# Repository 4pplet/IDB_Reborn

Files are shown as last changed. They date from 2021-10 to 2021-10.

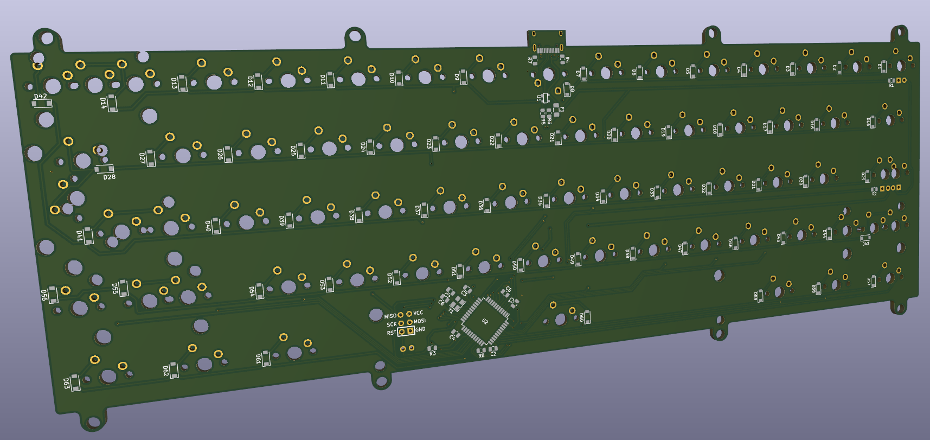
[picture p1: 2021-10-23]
Images/back.png

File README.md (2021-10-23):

# IDB_reborn
Reborn of the PCB for the IDB60

Made in KiCad Nightly

Originally designed by pngu.
Redigned by Mattelec.

Tested via private GB of the PCB. Might need some filing though.

Any question refer to Mattelec#9468 at Discord

Front

Back

Compatible layouts

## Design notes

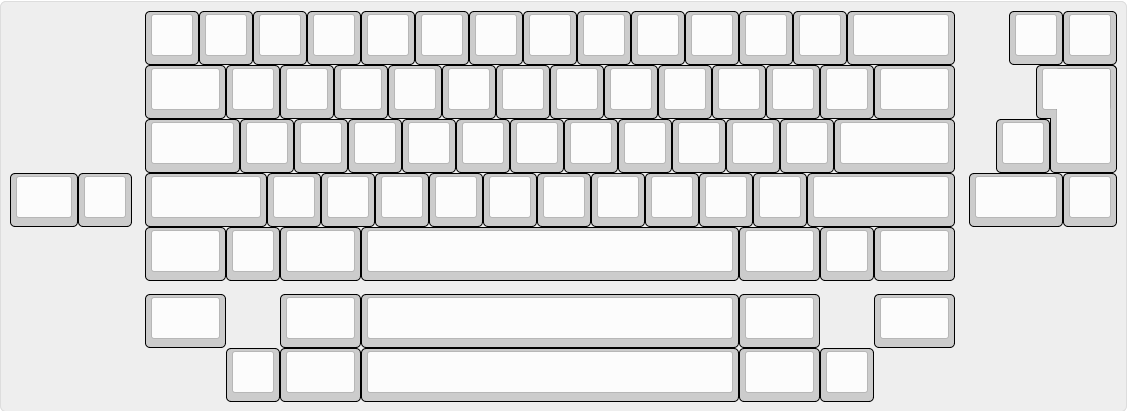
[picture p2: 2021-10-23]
Images/layout.png

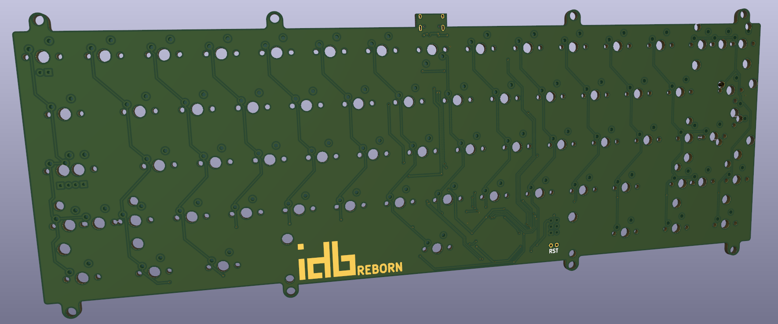
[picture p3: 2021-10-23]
Images/front.png

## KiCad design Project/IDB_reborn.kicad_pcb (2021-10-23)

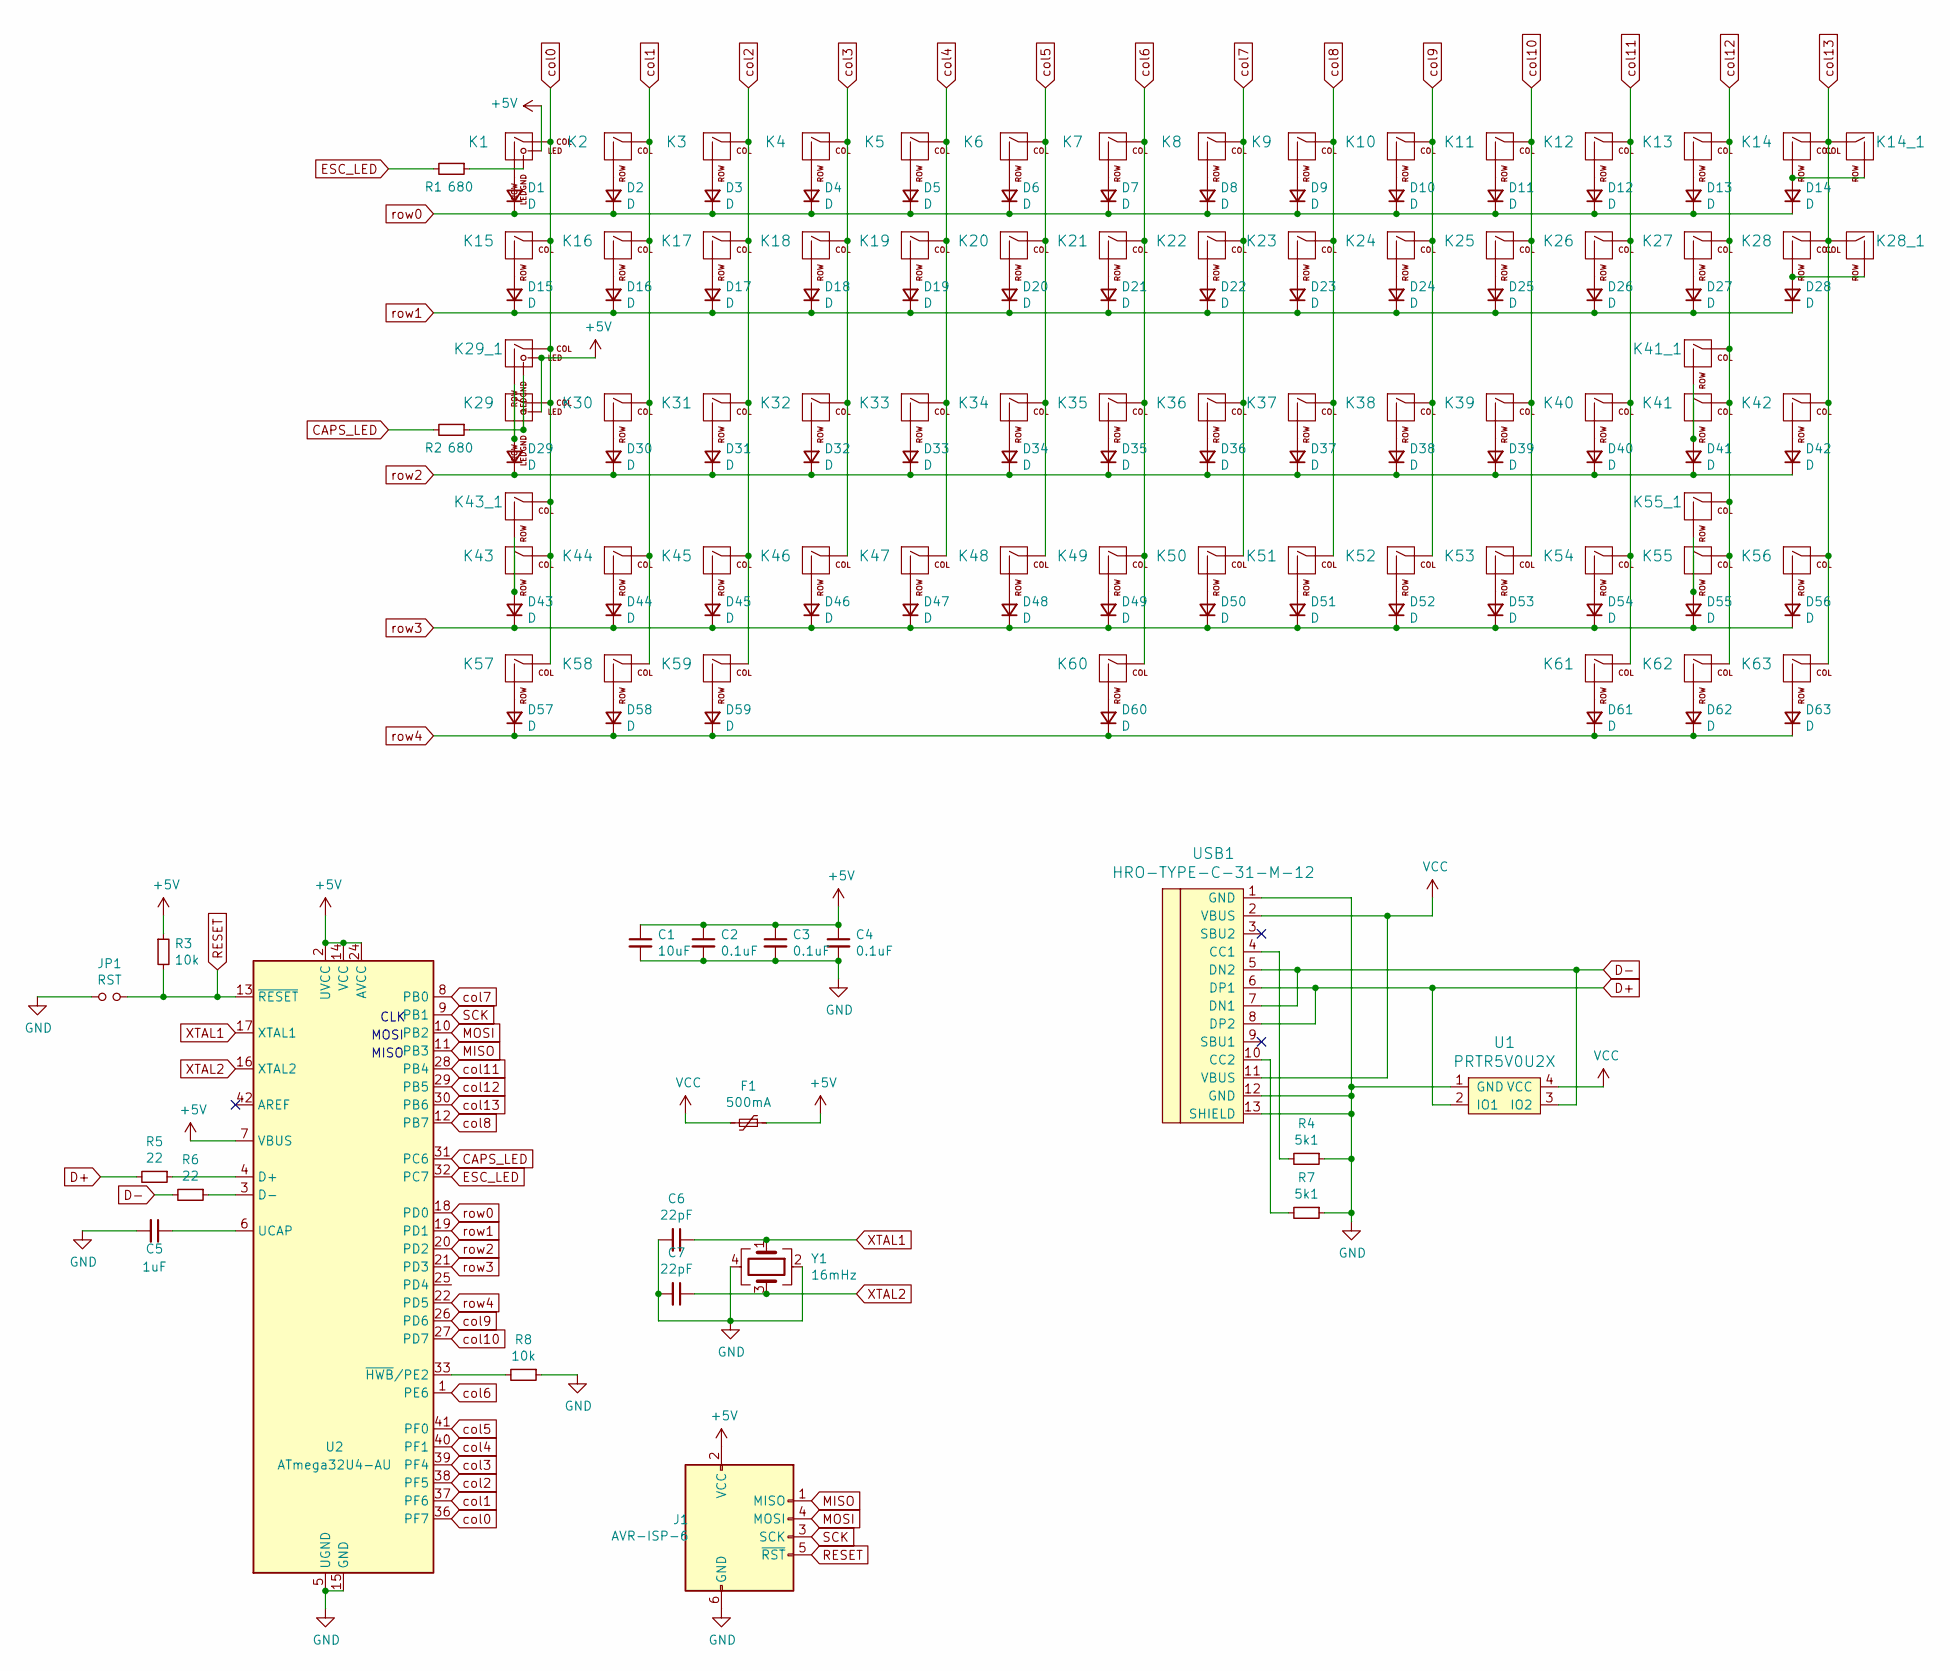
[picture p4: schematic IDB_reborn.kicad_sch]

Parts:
C1: 10uF; C_0805_2012Metric; LCSC C15850
C2, C3, C4: 0.1uF; C_0805_2012Metric; LCSC C49678
C5: 1uF; C_0805_2012Metric; LCSC C28323
C6, C7: 22pF; C_0805_2012Metric; LCSC C1804
D1, D2, D3, D4, D5, D6, D7, D8, D9, D10, D11, D12, D13, D14, D15, D16, D17, D18, D19, D20, D21, D22, D23, D24, D25, D26, D27, D28, D29, D30, D31, D32, D33, D34, D35, D36, D37, D38, D39, D40, D41, D42, D43, D44, D45, D46, D47, D48, D49, D50, D51, D52, D53, D54, D55, D56, D57, D58, D59, D60, D61, D62, D63: D; D_SOD-123-Pretty; LCSC C64898
F1: 500mA; Fuse_1206_3216Metric; LCSC C70076
J1: AVR-ISP-6; Reset_Pretty-Mask
JP1: RST; Reset_holes
K1: MXOnly-1U-19mm
K2, K3, K4, K5, K6, K7, K8, K9, K10, K11, K12, K13, K14_1, K16, K17, K18, K19, K20, K21, K22, K23, K24, K25, K26, K27, K30, K31, K32, K33, K34, K35, K36, K37, K38, K39, K40, K41, K42, K44, K45, K46, K47, K48, K49, K50, K51, K52, K53, K54, K56, K58, K62: MXOnly-1U-NoLED-19mm
K14: MXOnly-2U-NoLED-19mm
K15, K28, K57, K59, K61, K63: MXOnly-1.5U--NoLED19mm
K28_1: MXOnly-ISO-ROTATED-NoLED-19mm
K29: MXOnly-1.75U-19mm
K29_1: MXOnly-1.25U-ReverseLED19mm
K41_1, K43_1: MXOnly-2.25U-NoLED-19mm
K43: MXOnly-1.25U-NoLED-19mm
K55: MXOnly-1.75U-NoLED-19mm
K55_1: MXOnly-2.75U-NoLED-19mm
K60: MXOnly-7U-ReversedStabilizers-NoLED-19mm
R1, R2: 680; R_0805_2012Metric; LCSC C25324
R3, R8: 10k; R_0805_2012Metric; LCSC C17414
R4, R7: 5k1; R_0805_2012Metric; LCSC C118848
R5, R6: 22; R_0805_2012Metric; LCSC C416086
U1: PRTR5V0U2X; SOT143B; LCSC C78442
U2: ATmega32U4-AU; TQFP-44_10x10mm_P0.8mm; LCSC C44854
USB1: HRO-TYPE-C-31-M-12; HRO-TYPE-C-31-M-12-Assembly; LCSC C165948
Y1: 16mHz; Crystal_SMD_3225-4Pin_3.2x2.5mm; LCSC C13738

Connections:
+5V: C1.1, C2.1, C3.1, C4.1, F1.1, J1.2 (VCC), K1.3 (LED), K29.3 (LED), K29_1.3 (LED), R3.1, U2.2 (UVCC), U2.7 (VBUS), U2.14 (VCC), U2.24 (AVCC), U2.34 (VCC), U2.44 (AVCC)
CAPS_LED: R2.2, U2.31 (PC6)
D+: R5.2, U1.2 (IO1), USB1.6 (DP1), USB1.8 (DP2)
D-: R6.2, U1.3 (IO2), USB1.5 (DN2), USB1.7 (DN1)
ESC_LED: R1.2, U2.32 (PC7)
GND: C1.2, C2.2, C3.2, C4.2, C5.2, C6.2, C7.2, J1.6 (GND), JP1.1, R4.1, R7.1, R8.1, U1.1 (GND), U2.5 (UGND), U2.15 (GND), U2.23 (GND), U2.35 (GND), U2.43 (GND), USB1.1 (GND), USB1.12 (GND), USB1.13 (SHIELD), Y1.2, Y1.4; also elsewhere on the board
MISO: J1.1 (MISO), U2.11 (PB3)
MOSI: J1.4 (MOSI), U2.10 (PB2)
unnamed: C5.1, U2.6 (UCAP)
unnamed: D1.2 (A), K1.2 (ROW)
unnamed: D2.2 (A), K2.2 (ROW)
unnamed: D3.2 (A), K3.2 (ROW)
unnamed: D4.2 (A), K4.2 (ROW)
unnamed: D5.2 (A), K5.2 (ROW)
unnamed: D6.2 (A), K6.2 (ROW)
unnamed: D7.2 (A), K7.2 (ROW)
unnamed: D8.2 (A), K8.2 (ROW)
unnamed: D9.2 (A), K9.2 (ROW)
unnamed: D10.2 (A), K10.2 (ROW)
unnamed: D11.2 (A), K11.2 (ROW)
unnamed: D12.2 (A), K12.2 (ROW)
unnamed: D13.2 (A), K13.2 (ROW)
unnamed: D14.2 (A), K14.2 (ROW), K14_1.2 (ROW)
unnamed: D15.2 (A), K15.2 (ROW)
unnamed: D16.2 (A), K16.2 (ROW)
unnamed: D17.2 (A), K17.2 (ROW)
unnamed: D18.2 (A), K18.2 (ROW)
unnamed: D19.2 (A), K19.2 (ROW)
unnamed: D20.2 (A), K20.2 (ROW)
unnamed: D21.2 (A), K21.2 (ROW)
unnamed: D22.2 (A), K22.2 (ROW)
unnamed: D23.2 (A), K23.2 (ROW)
unnamed: D24.2 (A), K24.2 (ROW)
unnamed: D25.2 (A), K25.2 (ROW)
unnamed: D26.2 (A), K26.2 (ROW)
unnamed: D27.2 (A), K27.2 (ROW)
unnamed: D28.2 (A), K28.2 (ROW), K28_1.2 (ROW)
unnamed: D29.2 (A), K29.2 (ROW), K29_1.2 (ROW)
unnamed: D30.2 (A), K30.2 (ROW)
unnamed: D31.2 (A), K31.2 (ROW)
unnamed: D32.2 (A), K32.2 (ROW)
unnamed: D33.2 (A), K33.2 (ROW)
unnamed: D34.2 (A), K34.2 (ROW)
unnamed: D35.2 (A), K35.2 (ROW)
unnamed: D36.2 (A), K36.2 (ROW)
unnamed: D37.2 (A), K37.2 (ROW)
unnamed: D38.2 (A), K38.2 (ROW)
unnamed: D39.2 (A), K39.2 (ROW)
unnamed: D40.2 (A), K40.2 (ROW)
unnamed: D41.2 (A), K41.2 (ROW), K41_1.2 (ROW)
unnamed: D42.2 (A), K42.2 (ROW)
unnamed: D43.2 (A), K43.2 (ROW), K43_1.2 (ROW)
unnamed: D44.2 (A), K44.2 (ROW)
unnamed: D45.2 (A), K45.2 (ROW)
unnamed: D46.2 (A), K46.2 (ROW)
unnamed: D47.2 (A), K47.2 (ROW)
unnamed: D48.2 (A), K48.2 (ROW)
unnamed: D49.2 (A), K49.2 (ROW)
unnamed: D50.2 (A), K50.2 (ROW)
unnamed: D51.2 (A), K51.2 (ROW)
unnamed: D52.2 (A), K52.2 (ROW)
unnamed: D53.2 (A), K53.2 (ROW)
unnamed: D54.2 (A), K54.2 (ROW)
unnamed: D55.2 (A), K55.2 (ROW), K55_1.2 (ROW)
unnamed: D56.2 (A), K56.2 (ROW)
unnamed: D57.2 (A), K57.2 (ROW)
unnamed: D58.2 (A), K58.2 (ROW)
unnamed: D59.2 (A), K59.2 (ROW)
unnamed: D60.2 (A), K60.2 (ROW)
unnamed: D61.2 (A), K61.2 (ROW)
unnamed: D62.2 (A), K62.2 (ROW)
unnamed: D63.2 (A), K63.2 (ROW)
unnamed: K1.4 (LEDGND), R1.1
unnamed: K29.4 (LEDGND), K29_1.4 (LEDGND), R2.1
unnamed: R4.2, USB1.4 (CC1)
unnamed: R5.1, U2.4 (D+)
unnamed: R6.1, U2.3 (D-)
unnamed: R7.2, USB1.10 (CC2)
unnamed: R8.2, U2.33 (~HWB/PE2)
RESET: J1.5 (~RST), JP1.2, R3.2, U2.13 (~RESET); also elsewhere on the board
SCK: J1.3 (SCK), U2.9 (PB1)
VCC: F1.2, U1.4 (VCC), USB1.2 (VBUS), USB1.11 (VBUS)
XTAL1: C6.1, U2.17 (XTAL1), Y1.1
XTAL2: C7.1, U2.16 (XTAL2), Y1.3
col0: K1.1 (COL), K15.1 (COL), K29.1 (COL), K29_1.1 (COL), K43.1 (COL), K43_1.1 (COL), K57.1 (COL), U2.36 (PF7)
col1: K2.1 (COL), K16.1 (COL), K30.1 (COL), K44.1 (COL), K58.1 (COL), U2.37 (PF6)
col2: K3.1 (COL), K17.1 (COL), K31.1 (COL), K45.1 (COL), K59.1 (COL), U2.38 (PF5)
col3: K4.1 (COL), K18.1 (COL), K32.1 (COL), K46.1 (COL), U2.39 (PF4)
col4: K5.1 (COL), K19.1 (COL), K33.1 (COL), K47.1 (COL), U2.40 (PF1)
col5: K6.1 (COL), K20.1 (COL), K34.1 (COL), K48.1 (COL), U2.41 (PF0)
col6: K7.1 (COL), K21.1 (COL), K35.1 (COL), K49.1 (COL), K60.1 (COL), U2.1 (PE6)
col7: K8.1 (COL), K22.1 (COL), K36.1 (COL), K50.1 (COL), U2.8 (PB0)
col8: K9.1 (COL), K23.1 (COL), K37.1 (COL), K51.1 (COL), U2.12 (PB7)
col9: K10.1 (COL), K24.1 (COL), K38.1 (COL), K52.1 (COL), U2.26 (PD6)
col10: K11.1 (COL), K25.1 (COL), K39.1 (COL), K53.1 (COL), U2.27 (PD7)
col11: K12.1 (COL), K26.1 (COL), K40.1 (COL), K54.1 (COL), K61.1 (COL), U2.28 (PB4)
col12: K13.1 (COL), K27.1 (COL), K41.1 (COL), K41_1.1 (COL), K55.1 (COL), K55_1.1 (COL), K62.1 (COL), U2.29 (PB5)
col13: K14.1 (COL), K14_1.1 (COL), K28.1 (COL), K28_1.1 (COL), K42.1 (COL), K56.1 (COL), K63.1 (COL), U2.30 (PB6)
row0: D1.1 (K), D2.1 (K), D3.1 (K), D4.1 (K), D5.1 (K), D6.1 (K), D7.1 (K), D8.1 (K), D9.1 (K), D10.1 (K), D11.1 (K), D12.1 (K), D13.1 (K), D14.1 (K), U2.18 (PD0)
row1: D15.1 (K), D16.1 (K), D17.1 (K), D18.1 (K), D19.1 (K), D20.1 (K), D21.1 (K), D22.1 (K), D23.1 (K), D24.1 (K), D25.1 (K), D26.1 (K), D27.1 (K), D28.1 (K), U2.19 (PD1)
row2: D29.1 (K), D30.1 (K), D31.1 (K), D32.1 (K), D33.1 (K), D34.1 (K), D35.1 (K), D36.1 (K), D37.1 (K), D38.1 (K), D39.1 (K), D40.1 (K), D41.1 (K), D42.1 (K), U2.20 (PD2)
row3: D43.1 (K), D44.1 (K), D45.1 (K), D46.1 (K), D47.1 (K), D48.1 (K), D49.1 (K), D50.1 (K), D51.1 (K), D52.1 (K), D53.1 (K), D54.1 (K), D55.1 (K), D56.1 (K), U2.21 (PD3)
row4: D57.1 (K), D58.1 (K), D59.1 (K), D60.1 (K), D61.1 (K), D62.1 (K), D63.1 (K), U2.22 (PD5)

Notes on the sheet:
MOSI
MISO
CLK

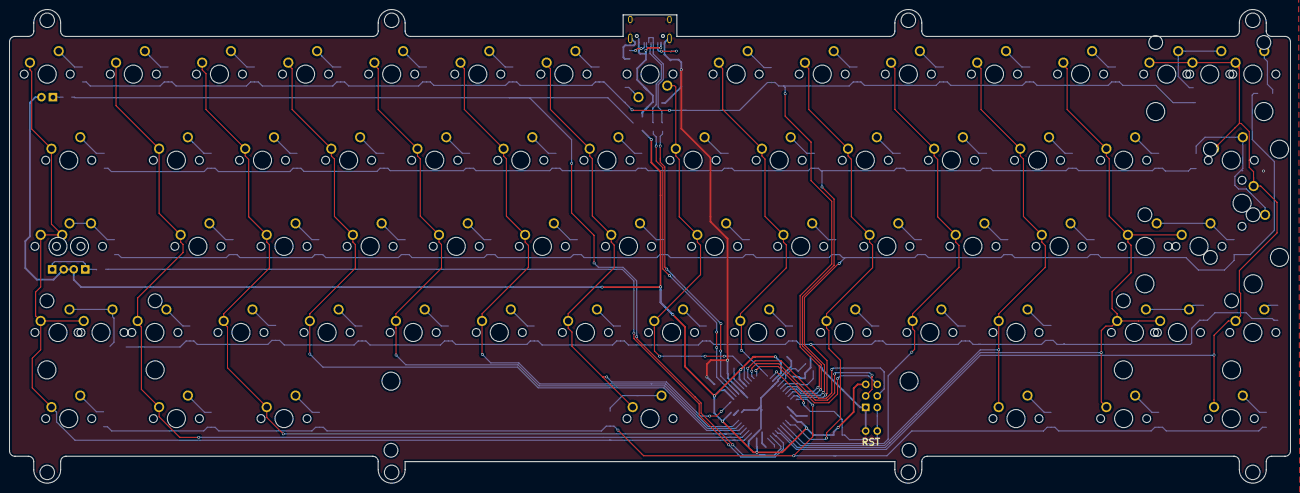
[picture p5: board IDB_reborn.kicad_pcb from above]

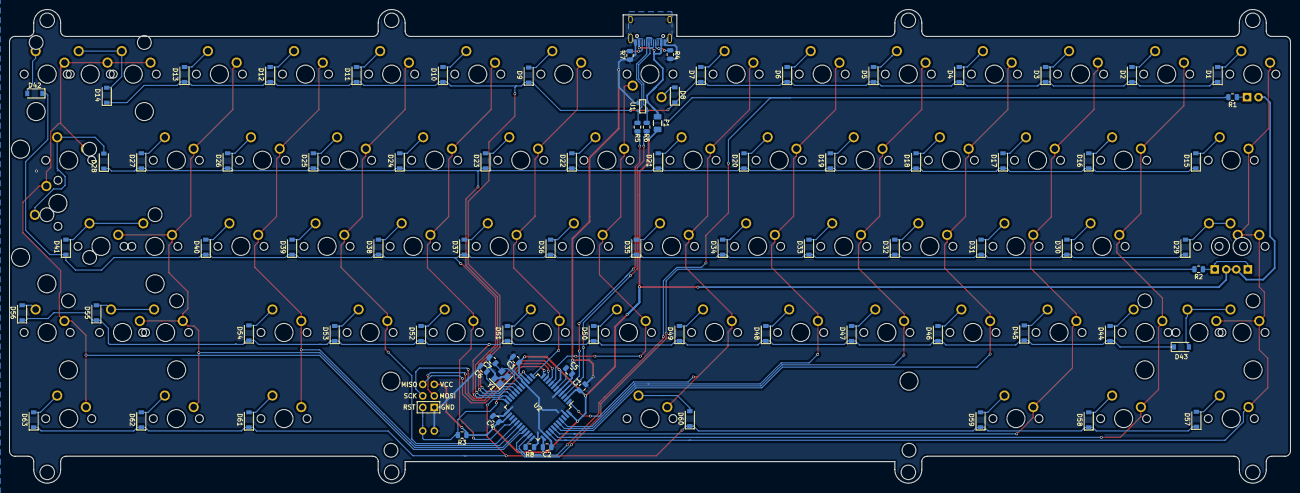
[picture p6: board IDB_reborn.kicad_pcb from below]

Board: 2 copper layers, 282.6 x 104.5 mm, 154 parts (84 on the bottom side), 103 nets.

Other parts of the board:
RST: JP1; Reset_holes

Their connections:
GND: RST.1; also elsewhere on the board
RESET: RST.2; also elsewhere on the board

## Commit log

2021-07-06 V1.0
    The start
    [IDB_remaster.kicad_pcb, IDB_remaster.sch]
2021-10-23 Added Gerber files
    [IDB_reborn-B_Cu.gbl, IDB_reborn-B_Mask.gbs, IDB_reborn-B_Silkscreen.gbo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]
